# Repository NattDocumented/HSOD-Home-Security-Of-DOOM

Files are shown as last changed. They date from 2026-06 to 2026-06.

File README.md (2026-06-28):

# H.S.O.D. : Home Security Of DOOM

A simple home security alarm with personality and a little twist ***wink*** ***wink***.

## What is it?

It is just like your simple, ordinary home security/alarm system. If you input your PIN to arm or disarm the alarm, and if you proceed to enter your PIN just in time, the alarm won't go off. However, when H.S.O.D went off... It doesn't just play a normal alarm... I will scare the burglar away (hopefully)... it plays a pre-recorded audio which you can customize/add custom audio to your liking, of how you would like to torment your burglar.

My personal option is DOOM ETERNAL MUSIC INTRO with + "so you are the chosen one."

## How do you use it?

It is very simple, here's how to use it!

### 1. Arming the Device
* **Action:** On boot, the system is disarmed. Input the PIN.
* **Outcome:** The current state of the device will change from unarmed to armed, and the OLED display and an audio cue from the speaker will indicate that!

### 2. INTRUDER ALERT!!!
* **Action:** Human detected.
* **Outcome:** The device enters a warning state or a countdown state, to be exact. The OLED display and a countdown coming from the speaker tracking your remaining time will also indicate that!

### 3. Disarming the Device
* **Action:** Input the PIN.
* **Outcome:**
  * **Correct PIN:** Everything resets and goes back to normal (back to the unarmed/disarmed state), the OLED display and the sound cue will also indicate it as well!
  * **Incorrect PIN:** Everything continues, but you can still go ahead and try again until the countdown reaches zero (but there's also a max attempt)

## System Architecture

```mermaid

graph TD;
  %%Define styles
  classDef controller fill:
  classDef sensor fill:
  classDef output fill:
  classDef cloud fill:

  %% Nodes
  Radar[HLK-LD2410C]:::sensor
  Mic[ICS-43434]:::sensor
  Keypad[Keypad]:::sensor

  MCU[Arduino Nano ESP32]:::controller

  OLED[OLED Display]:::output
  DFPlayer[DFPlayer Mini + Speaker]:::output

  Wit[Wit.ai Speech API]:::cloud

  %% Connections
  Radar --> |UART2 / Pin D11 Trigger| MCU
  Mic --> | I2S Mono PCM via DMA | MCU
  Keypad --> |Digital I/O Pins 2-8| MCU

  MCU --> |Hardware I2C| OLED
  MCU --> |Hardware UART1| DFPlayer
  MCU -.-> |Chunked HTTPS POST| Wit

```

## State Machine

```mermaid

stateDiagram-v2
  [*] --> STATE_DISARMED : Boot

  STATE_DISARMED --> STATE_ARMED : Enter PIN + ENT

  STATE_ARMED --> STATE_COUNTDOWN : Human Detected

  STATE_COUNTDOWN --> STATE_DISARMED : Correct PIN / Voice Phrase <br> Entered 
  STATE_COUNTDOWN --> STATE_ALARM : Timer Hits 0

  STATE_ALARM --> STATE_DISARMED : Correct PIN / Voice Phrase <br> Entered 
  STATE_ALARM --> STATE_LOCKED_OUT : Too Many Failed Attempts

  STATE_LOCKED_OUT --> STATE_ARMED  

```

## Why did I make it?

Here's a little back story. I passed an entrance exam to one of the best high schools in Thailand (Triam Udom Suksa School, btw ***wink*** ***wink***), which means I have to move away and live alone in the big city, but, being a country boy, I came up with an idea. Wouldn't it be so fitting to add some security measures to my apartment because I'm living alone? Normal Securities are boring, corporate, no personality, there's nothing interesting, so I came up with something new of my own! I came up with this!

## Step-By-Step Build Guide.

### Tools Required
* **Soldering Iron & Solder Wire** 
* **Wire Flush Cutters**
* **Tweezers**

---

### [1] : Prep Your MicroSD Card

1. Insert your **MicroSD card** into your computer and format it to **FAT32**.
2. Drop your custom audio files inside (`0001.mp3`, `0002.mp3`, etc.)
   
   *  `0001.mp3` = Warning beep
   *  `0002.mp3` = Full alarm audio
   *  `0003.mp3` = Armed sound
   *  `0004.mp3` = Disarmed sound
   *  `0005.mp3` = Incorrect sound
   *  `0006.mp3` = Locked out sound
   *  `0007.mp3` = Startup sound

3. Eject the card and insert it right into the slot of the **DFPlayer Mini (U3)**.

### [2] : Soldering Components

This is fairly simple due to each component having its own designated spots on the board; simply find those and solder them in place.

**For Example/Demonstration:**
1. **Keypad:** Insert the 12 **Cherry MX Mechanical Switches (SW1 to SW12)** into the **big key grid squares** on the board. If you can't see it, I'm going to assume you're blind (I'm just playing with ya lol), flip it over, and solder, **simple!**
2. **Modules:** as stated, the OLED Display, Arduino Nano ESP32, HLK-LD2410C, and all the components and modules all have their own slot, just insert them into their own spot, **flip 'em over, and solder!** **simple!**

I think you get it now, simple! Isn't it?
All you have to do is do the same thing for every component of this device.

**Tips, but kind of necessarily:** After soldering everything, use your **Wire Flush Cutters** to cut the excess leads or pins off.

### [3] : Uploading Firmware (PlatformIO)

This project is built using **PlatformIO** which is inside of VS Code instead of the standard Arduino IDE. Here's how to flash the firmware:

#### 1. Clone the Project

```bash
git clone https://github.com/NattDocumented/HSOD-Home-Security-Of-DOOM.git
```

#### 2. Open in VS Code
1. Launch **Visual Studio Code**.
2. Make sure you have the **PlatformIO IDE** extension installed; if not, go ahead and install it.
3. Click `File` > `Open Folder...` from the top menu, navigate to the folder you just cloned, and click **Open**. (Make sure you open the root folder containing the `platformio.ini` file)

#### 3. Making Voice Unlock Works

1. Login to [Wit.ai](https://wit.ai) with your Meta (a.k.a. Facebook) account.
2. If done correctly, it should lead you to the dashboard/apps, if not [click this](https://wit.ai/apps).
3. Click **+ New App** to create a new app **(obviously)**. You can name it whatever you please, but I personally just named it `"hsod"`.
4. Go into your newly created app. You'll see a sidebar. Click on **Management**, and go to **Settings**.
5. Copy your **Client Access Token** and replace these line in the firmware's code.
   
    ```cpp
    const char* WIFI_SSID = "YOUR_WIFI_SSID"; // Your WiFi's SSID
    const char* WIFI_PASS = "YOUR_WIFI_PASSWORD"; // Your WiFi Password here
    const char* WIT_TOKEN = "YOUR_WIT_AI_TOKEN"; // Your Wit.ai's token here
    ```

#### 4. Build and Upload
1. Connect a USB-C data cable from your computer into your Arduino Nano ESP32 port.
2. Click the **PlatformIO Alien Icon** on the left menu bar.
3. Under the Project Tasks menu, click **Build** to compile the codebase.
4. Once the terminal displays a green `[SUCCESS]` message, click **Upload** right below it to flash the firmware onto your board.

#### 5. Done
As soon as the upload completes, the OLED screen will wake up, and the speaker will play the system startup sound.

### [4] : Casing / Enclosure

After finishing the other steps, I think this one is the easiest, so don't be tired yet, lmao.

1. **Have your 3D printed casing / Enclosure ready:** if you haven't done that, go ahead and print it, no rush, because this README.md can't run away from you lmao.
2. **Assemble:** This is easy. There should be 2 parts: the base and the lid. Since there are poles on the base and holes on the PCB for assembly, simply insert the PCB into the enclosure while making sure the USB of the Arduino Nano ESP32 is right where the hole for the USB on the casing is. After, just put the base and lids together while making sure all the components that should be visible are visible. Both the base and the lid have sockets for connecting to each other.
3. **Done!**

#### You can now enjoy this amazing device. Hope you have a great experience. Any feedback is appreciated.

## Gallery

### Finished Product Renders
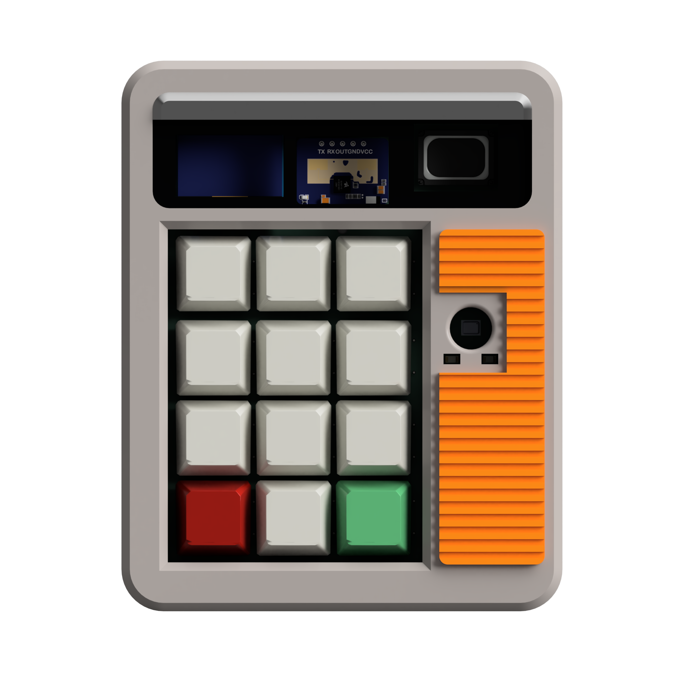
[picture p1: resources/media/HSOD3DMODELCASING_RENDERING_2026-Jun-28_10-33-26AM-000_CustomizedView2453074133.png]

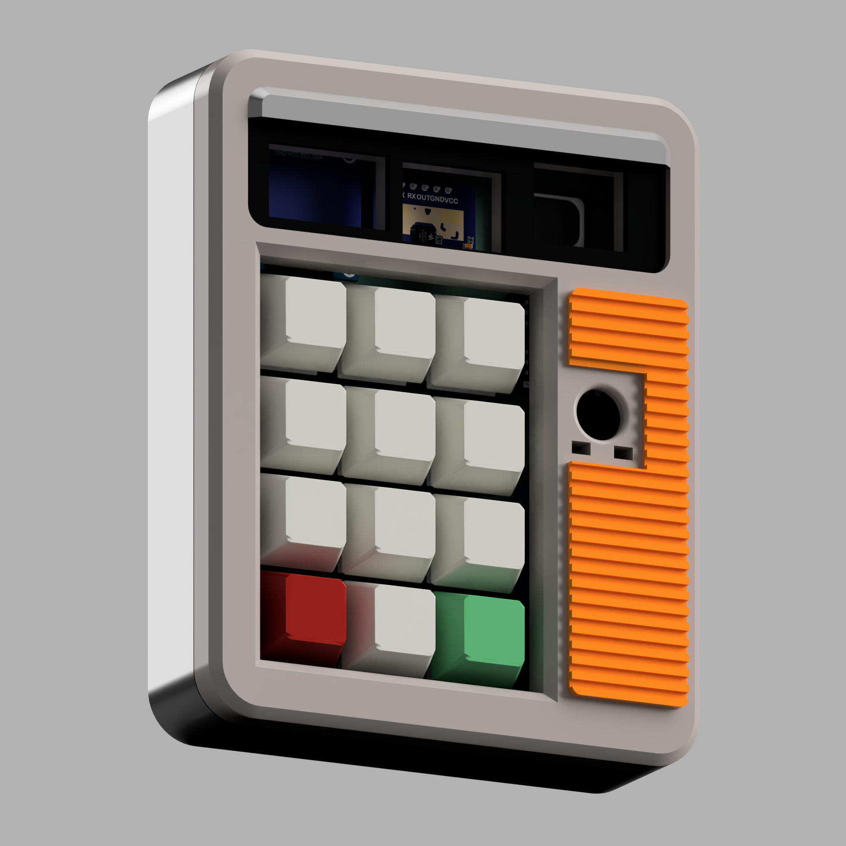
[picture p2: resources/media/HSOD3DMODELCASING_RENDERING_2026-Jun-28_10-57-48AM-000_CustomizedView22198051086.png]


### Schematics

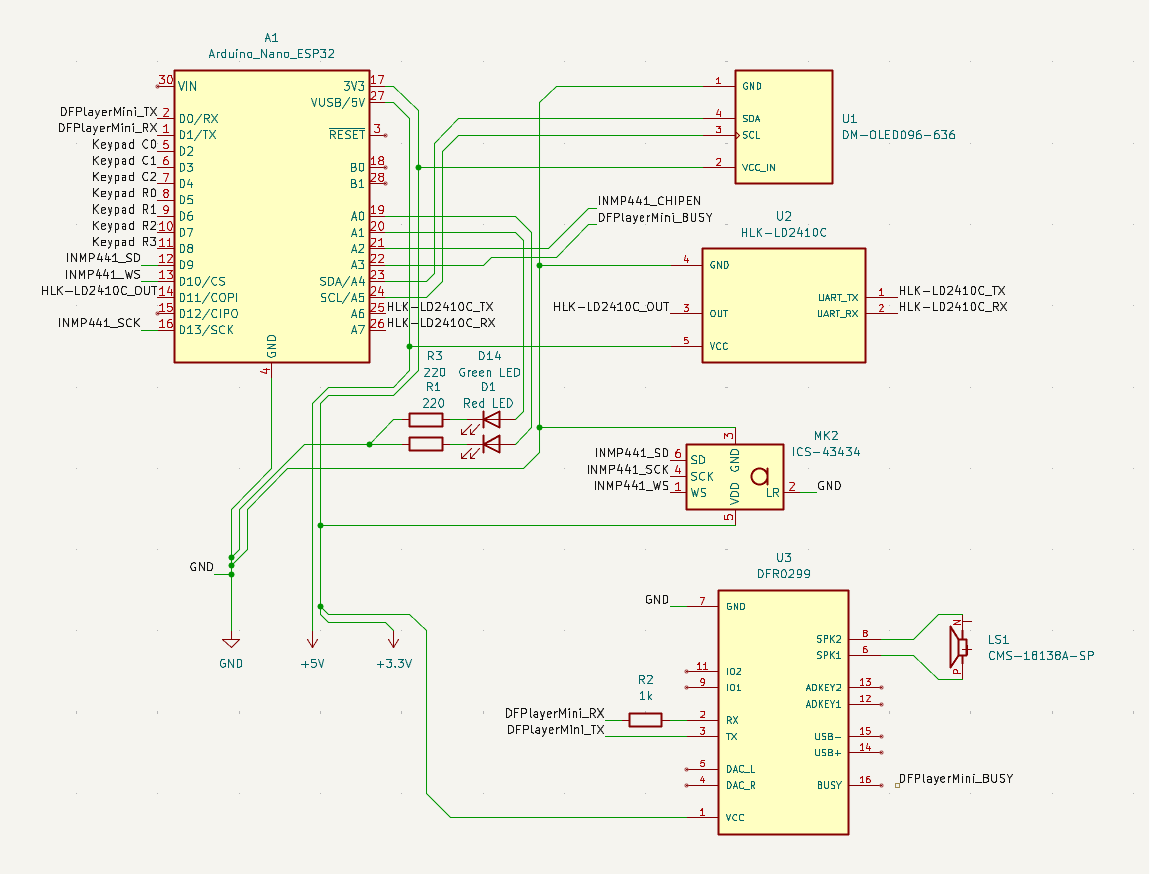
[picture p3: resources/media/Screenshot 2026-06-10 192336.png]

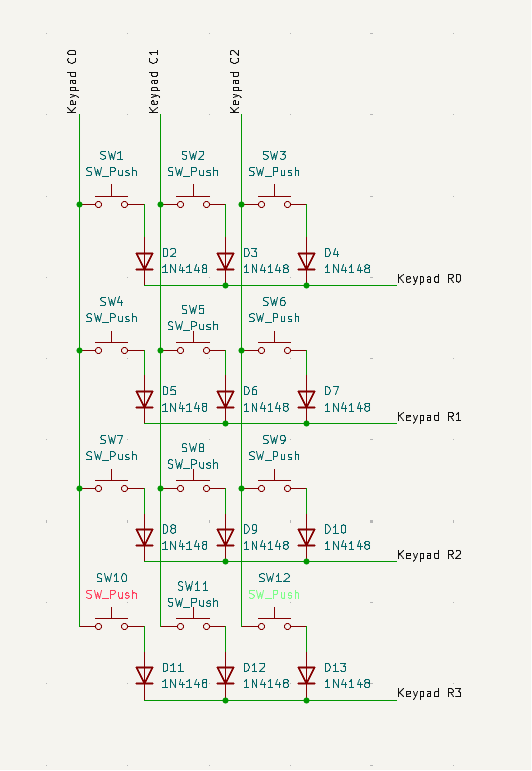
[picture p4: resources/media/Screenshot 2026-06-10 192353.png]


### PCBs

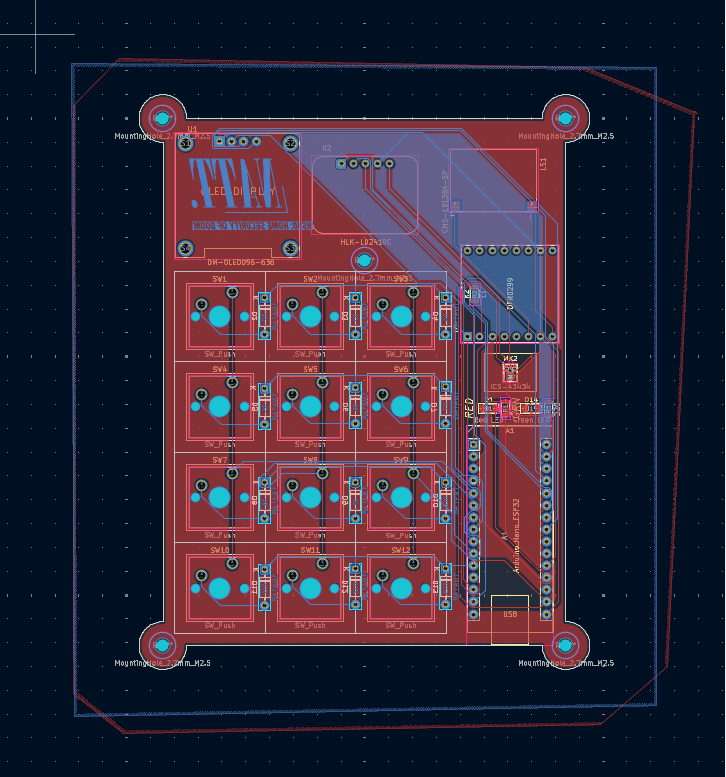
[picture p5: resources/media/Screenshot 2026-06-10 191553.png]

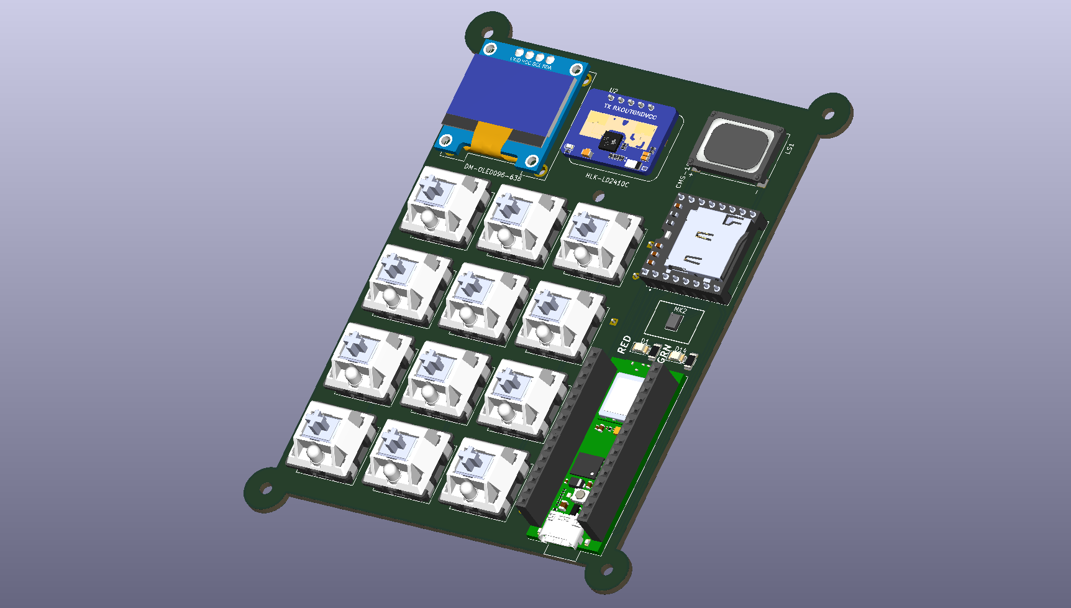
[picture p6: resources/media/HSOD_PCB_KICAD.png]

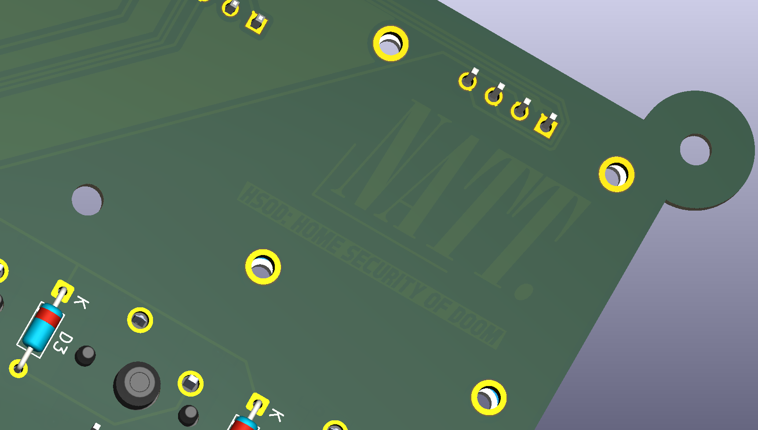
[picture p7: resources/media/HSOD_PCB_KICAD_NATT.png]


### Casing / Enclosure Design

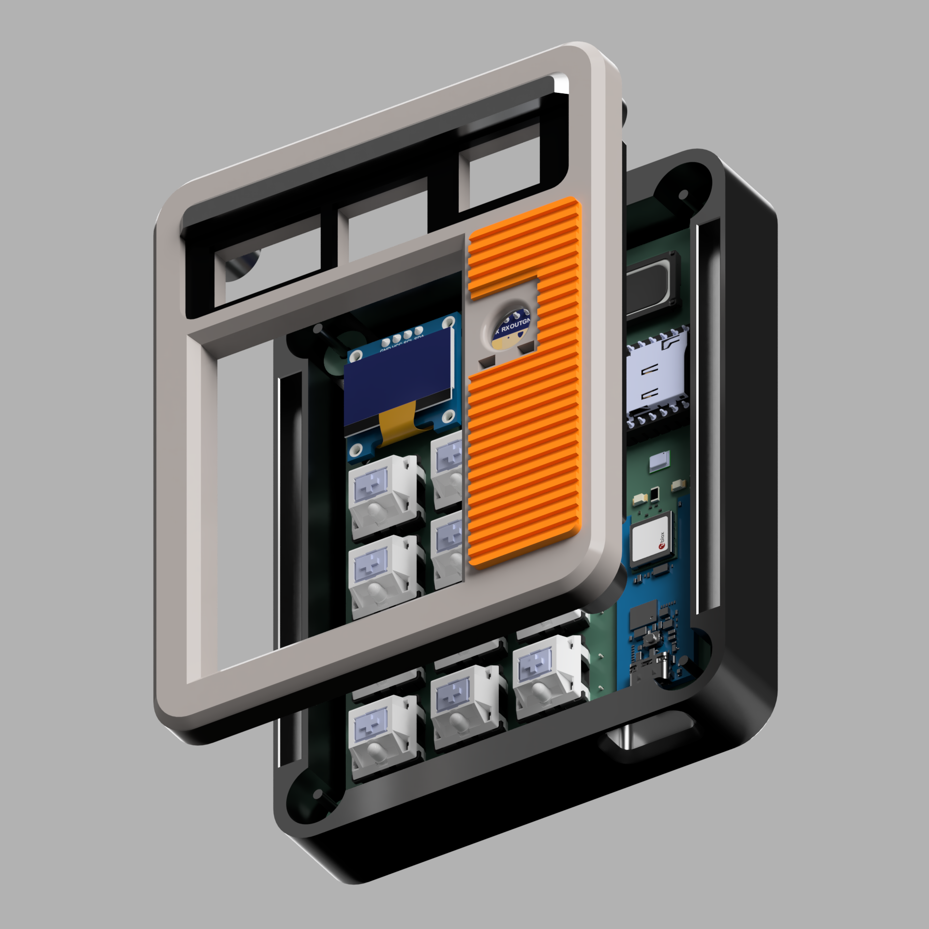
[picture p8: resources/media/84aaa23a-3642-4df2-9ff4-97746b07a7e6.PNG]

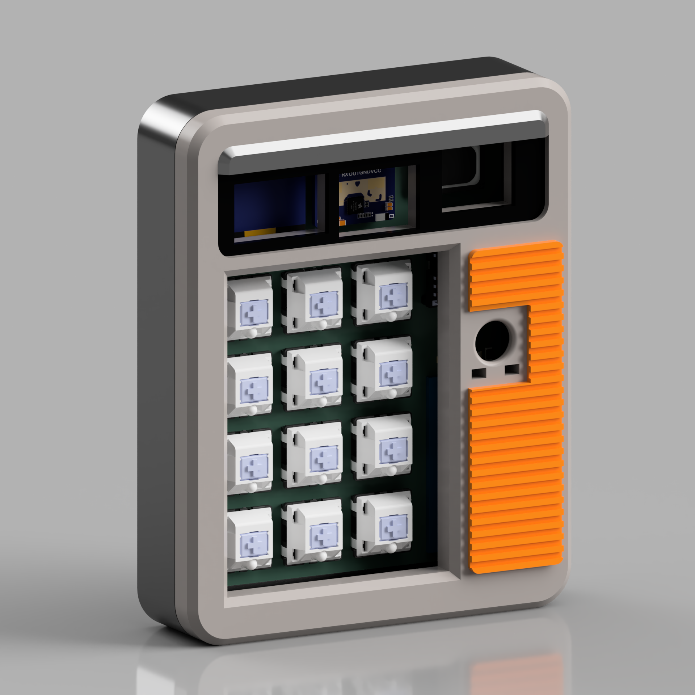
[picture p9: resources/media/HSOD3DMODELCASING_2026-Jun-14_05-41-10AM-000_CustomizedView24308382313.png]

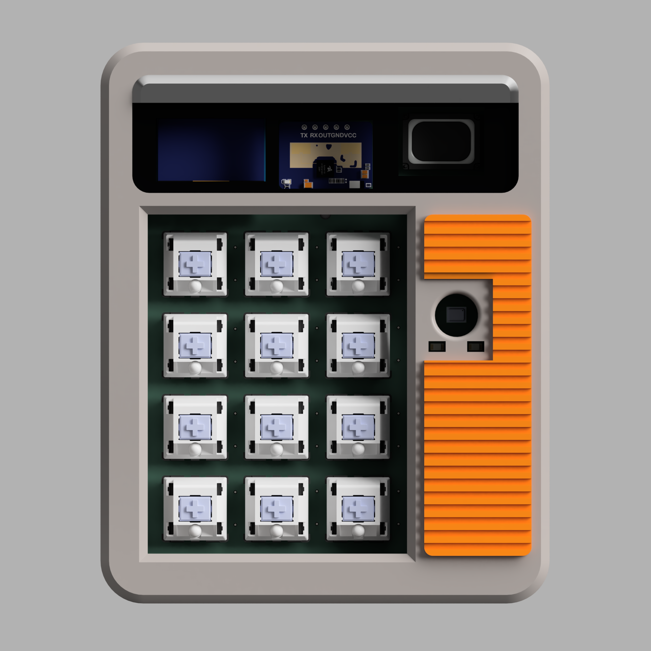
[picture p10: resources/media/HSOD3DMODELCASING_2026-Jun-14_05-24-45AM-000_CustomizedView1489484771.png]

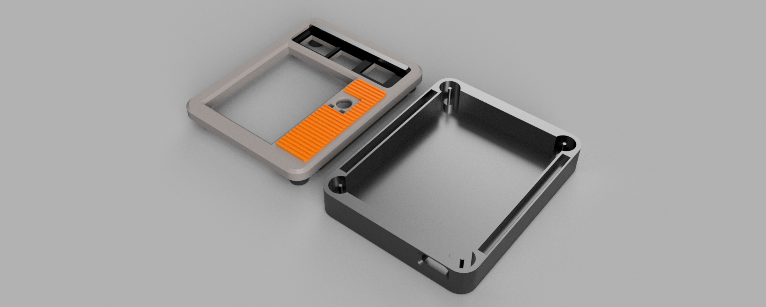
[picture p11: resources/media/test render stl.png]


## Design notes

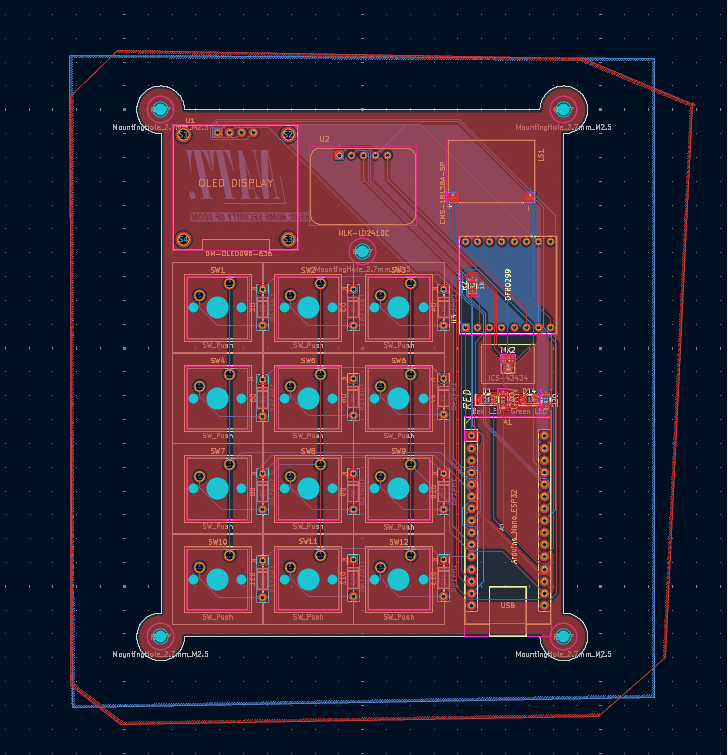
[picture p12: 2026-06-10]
resources/media/Screenshot 2026-06-10 191414.png

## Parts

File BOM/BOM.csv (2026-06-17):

Name/Value | Qty | Qty (pcs) | Reference | Footprint | Source | Datasheet | Unit Cost (USD) | Total Line Cost (USD)
Arduino Nano ESP32 | 1 | 1 | A1 | Module:Arduino_Nano | https://th.aliexpress.com/item/1005010222434725.html?curPageLogUid=WB2ngV9cbQay | https://docs.arduino.cc/resources/datasheets/ABX00083-datasheet.pdf | $20.42 | $20.42
1N4148 Switching Diodes (100 pcs) | 1 | 12 | D2,D3,D4,D5,D6,D7,D8,D9,D10,D11,D12,D13 | Diode_THT:D_DO-35_SOD27_P7.62mm_Horizontal | https://th.aliexpress.com/item/1005008546139991.html?curPageLogUid=1k5XOGo850Vm | https://assets.nexperia.com/documents/data-sheet/1N4148_1N4448.pdf | $0.61 | $0.61
LED SMD (5 color: Red,Green,Blue,White,Yellow | 100 pcs | 20 pcs/color) | 1 | 2 | D14 (Green),D1 (Red) | LED_SMD:LED_1206_3216Metric | https://th.aliexpress.com/item/1005010516045797.html?curPageLogUid=vBj5sSL6c7mr | https://cdn-reichelt.de/documents/datenblatt/A500/SMD1206_ENG_TDS.pdf | $1.17 | $1.17
8 Ohm 1W (CMS-18138A-SP) | 1 | 1 | LS1 | CMS-18138A-SP:CUI_CMS-18138A-SP | https://www.mouser.com/ProductDetail/Same-Sky/CMS-18138A-SP?qs=EU6FO9ffTweZnPPJ%252Bd4HzA%3D%3D | https://th.mouser.com/datasheet/3/6118/1/cms_18138a_sp.pdf | $4.25 | $4.25
ICS-43434 Digital I2S Microphone | 1 | 1 | MK2 | Sensor_Audio:InvenSense_ICS-43434-6_3.5x2.65mm | https://th.mouser.com/ProductDetail/TDK-InvenSense/ICS-43434?qs=u4fy%2FsgLU9PAgmWRI7%252BqXA%3D%3D | https://www.invensense.com/wp-content/uploads/2016/02/DS-000069-ICS-43434-v1.2.pdf | $3.27 | $3.27
220 Ohm Resistors (300 pcs) | 2 | 2 | R1,R3 | Resistor_SMD:R_1206_3216Metric | https://th.aliexpress.com/item/1005011756381896.html?curPageLogUid=rDaOGspg5KaQ | https://www.vishay.com/docs/60093/fcseries.pdf | $1.31 | $2.62
1k Ohm Resistor (300 pcs) | 1 | 1 | R2 | Resistor_SMD:R_1206_3216Metric | https://th.aliexpress.com/item/1005011756381896.html?curPageLogUid=rDaOGspg5KaQ | https://www.vishay.com/docs/60093/fcseries.pdf | $1.33 | $1.33
Cherry MX Mechanical Switches (No RGB,10 pcs) | 2 | 12 | SW1,SW2,SW3,SW4,SW5,SW6,SW7,SW8,SW9,SW10,SW11,SW12 | Button_Switch_Keyboard:SW_Cherry_MX_1.00u_PCB | https://th.aliexpress.com/item/1005007891400560.html?curPageLogUid=uYAcDnG8VaiJ | https://cdn.sparkfun.com/datasheets/Components/Switches/MX%20Series.pdf | $3.64 | $7.28
0.96" I2C 128X64 SSD1306 OLED Display | 1 | 1 | U1 | Oled from idk 001:MODULE_DM-OLED096-636 | https://th.aliexpress.com/item/32896971385.html?curPageLogUid=fn6mKh68Id5Y | - | $1.23 | $1.23
HLK-LD2410C 24GHz Radar Module | 1 | 1 | U2 | HLK-LD2410C:MODULE_HLK-LD2410C | https://th.aliexpress.com/item/1005005047841163.html?curPageLogUid=WBC80ioCXF8C | https://drive.google.com/drive/folders/1ypOlacBmmFXY6lDQ0f1hEJFmczNe-0WG | $1.51 | $1.51
DFPlayer Mini (DFR0299) | 1 | 1 | U3 | DFR0299:MODULE_DFR0299 | https://th.aliexpress.com/item/1005006166800318.html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 | https://dfimg.dfrobot.com/wiki/20532/DFR0299_mp3-player-module_datasheet_V1.0.pdf | $1.07 | $1.07
SanDisk Ultra MicroSD Card 32GB | 1 | 1 | - | - | https://th.aliexpress.com/item/1005007498167692.html?curPageLogUid=lMcXFdEWEGLv | - | $7.61 | $7.61
PCB Fabrication | 1 | 1 | - | - | https://jlcpcb.com/quote | - | $8.60 | $8.60
 |  |  |  |  |  | Estimated total cost (USD): | $60.97

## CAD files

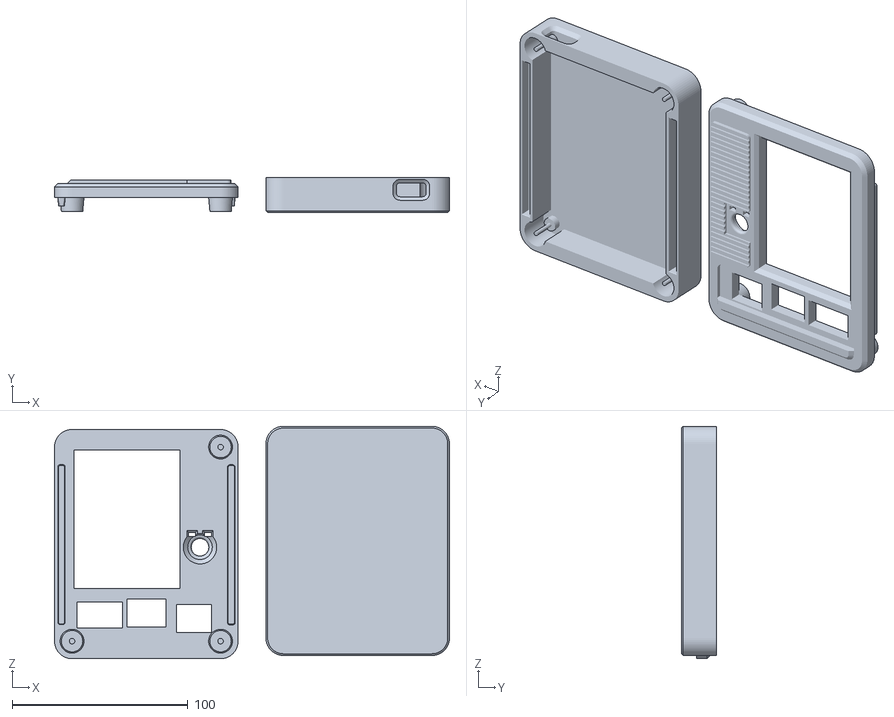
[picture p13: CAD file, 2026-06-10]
STLs/hsod_case_1printfinish.stl
225.0 x 20.0 x 132.4

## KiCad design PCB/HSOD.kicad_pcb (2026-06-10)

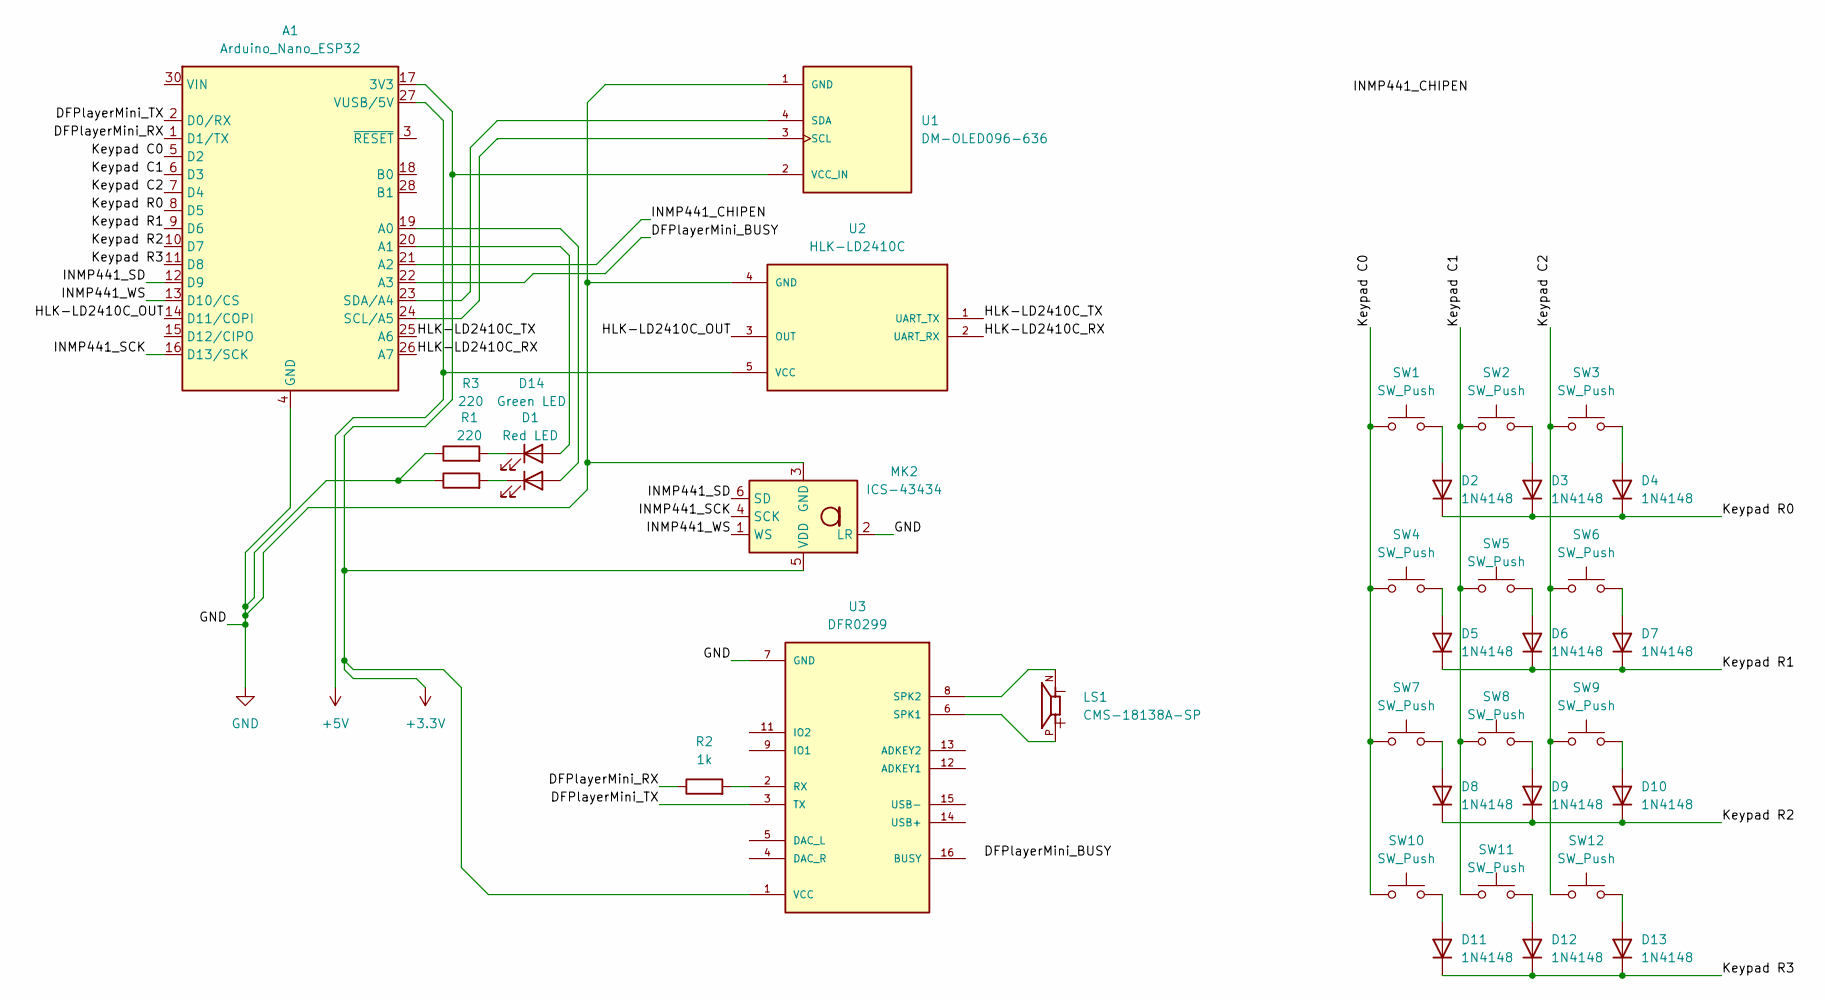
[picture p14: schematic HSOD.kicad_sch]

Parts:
A1: Arduino_Nano_ESP32; Arduino_Nano
D1: Red LED; LED_1206_3216Metric
D2, D3, D4, D5, D6, D7, D8, D9, D10, D11, D12, D13: 1N4148; D_DO-35_SOD27_P7.62mm_Horizontal
D14: Green LED; LED_1206_3216Metric
LS1: CMS-18138A-SP; CUI_CMS-18138A-SP
MK2: ICS-43434; InvenSense_ICS-43434-6_3.5x2.65mm
R1, R3: 220; R_1206_3216Metric
R2: 1k; R_1206_3216Metric
SW1, SW2, SW3, SW4, SW5, SW6, SW7, SW8, SW9, SW10, SW11, SW12: SW_Push; SW_Cherry_MX_1.00u_PCB
U1: DM-OLED096-636; MODULE_DM-OLED096-636; PARTREV 2018-09-10
U2: HLK-LD2410C; MODULE_HLK-LD2410C; PARTREV V1.00
U3: DFR0299; MODULE_DFR0299

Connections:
+3.3V: A1.17 (3V3), MK2.5 (VDD), U1.2 (VCC_IN), U3.1 (VCC)
+5V: A1.27 (VUSB/5V), U2.5 (VCC)
/DFPlayerMini_BUSY: A1.22 (A3)
/DFPlayerMini_RX: A1.1 (D1/TX), R2.1
/DFPlayerMini_TX: A1.2 (D0/RX), U3.3 (TX)
/HLK-LD2410C_OUT: A1.14 (D11/COPI), U2.3 (OUT)
/HLK-LD2410C_RX: A1.26 (A7), U2.2 (UART_RX)
/HLK-LD2410C_TX: A1.25 (A6), U2.1 (UART_TX)
/INMP441_CHIPEN: A1.21 (A2)
/INMP441_SCK: A1.16 (D13/SCK), MK2.4 (SCK)
/INMP441_SD: A1.12 (D9), MK2.6 (SD)
/INMP441_WS: A1.13 (D10/CS), MK2.1 (WS)
/Keypad C0: A1.5 (D2), SW1.1, SW4.1, SW7.1, SW10.1
/Keypad C1: A1.6 (D3), SW2.1, SW5.1, SW8.1, SW11.1
/Keypad C2: A1.7 (D4), SW3.1, SW6.1, SW9.1, SW12.1
/Keypad R0: A1.8 (D5), D2.1 (K), D3.1 (K), D4.1 (K)
/Keypad R1: A1.9 (D6), D5.1 (K), D6.1 (K), D7.1 (K)
/Keypad R2: A1.10 (D7), D8.1 (K), D9.1 (K), D10.1 (K)
/Keypad R3: A1.11 (D8), D11.1 (K), D12.1 (K), D13.1 (K)
GND: A1.4 (GND), A1.29 (GND), MK2.2 (LR), MK2.3 (GND), R1.1, R3.1, U1.1 (GND), U2.4 (GND), U3.7 (GND), U3.10 (GND)
unnamed: A1.19 (A0), D1.2 (A)
unnamed: A1.20 (A1), D14.2 (A)
unnamed: A1.24 (SCL/A5), U1.3 (SCL)
unnamed: A1.23 (SDA/A4), U1.4 (SDA)
unnamed: D1.1 (K), R1.2
unnamed: D2.2 (A), SW1.2
unnamed: D3.2 (A), SW2.2
unnamed: D4.2 (A), SW3.2
unnamed: D5.2 (A), SW4.2
unnamed: D6.2 (A), SW5.2
unnamed: D7.2 (A), SW6.2
unnamed: D8.2 (A), SW7.2
unnamed: D9.2 (A), SW8.2
unnamed: D10.2 (A), SW9.2
unnamed: D11.2 (A), SW10.2
unnamed: D12.2 (A), SW11.2
unnamed: D13.2 (A), SW12.2
unnamed: D14.1 (K), R3.2
unnamed: R2.2, U3.2 (RX)
unnamed: LS1.P, U3.6 (SPK1)
unnamed: LS1.N, U3.8 (SPK2)

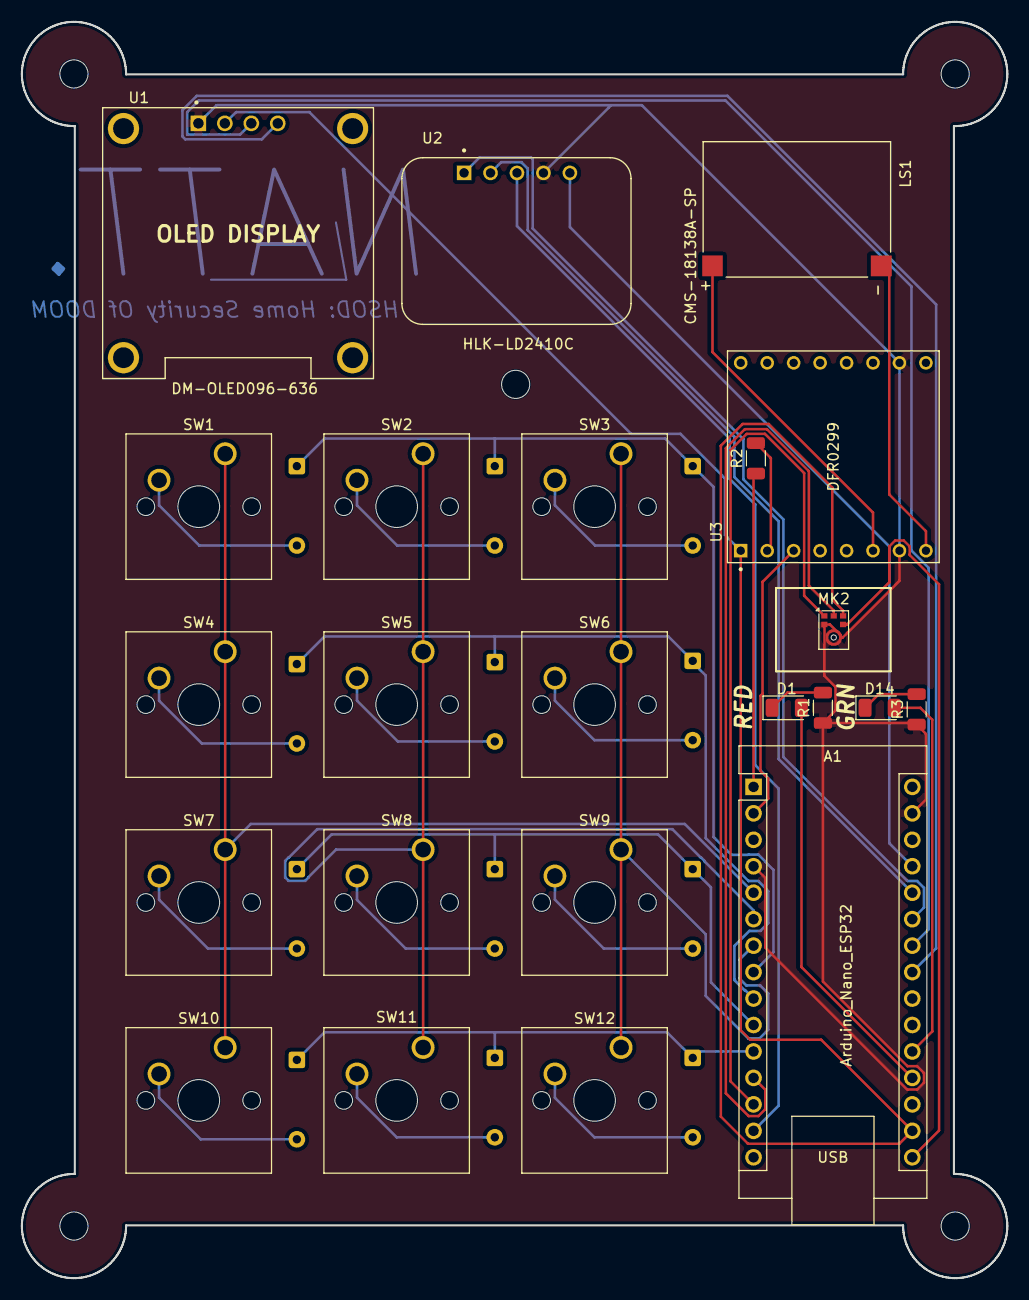
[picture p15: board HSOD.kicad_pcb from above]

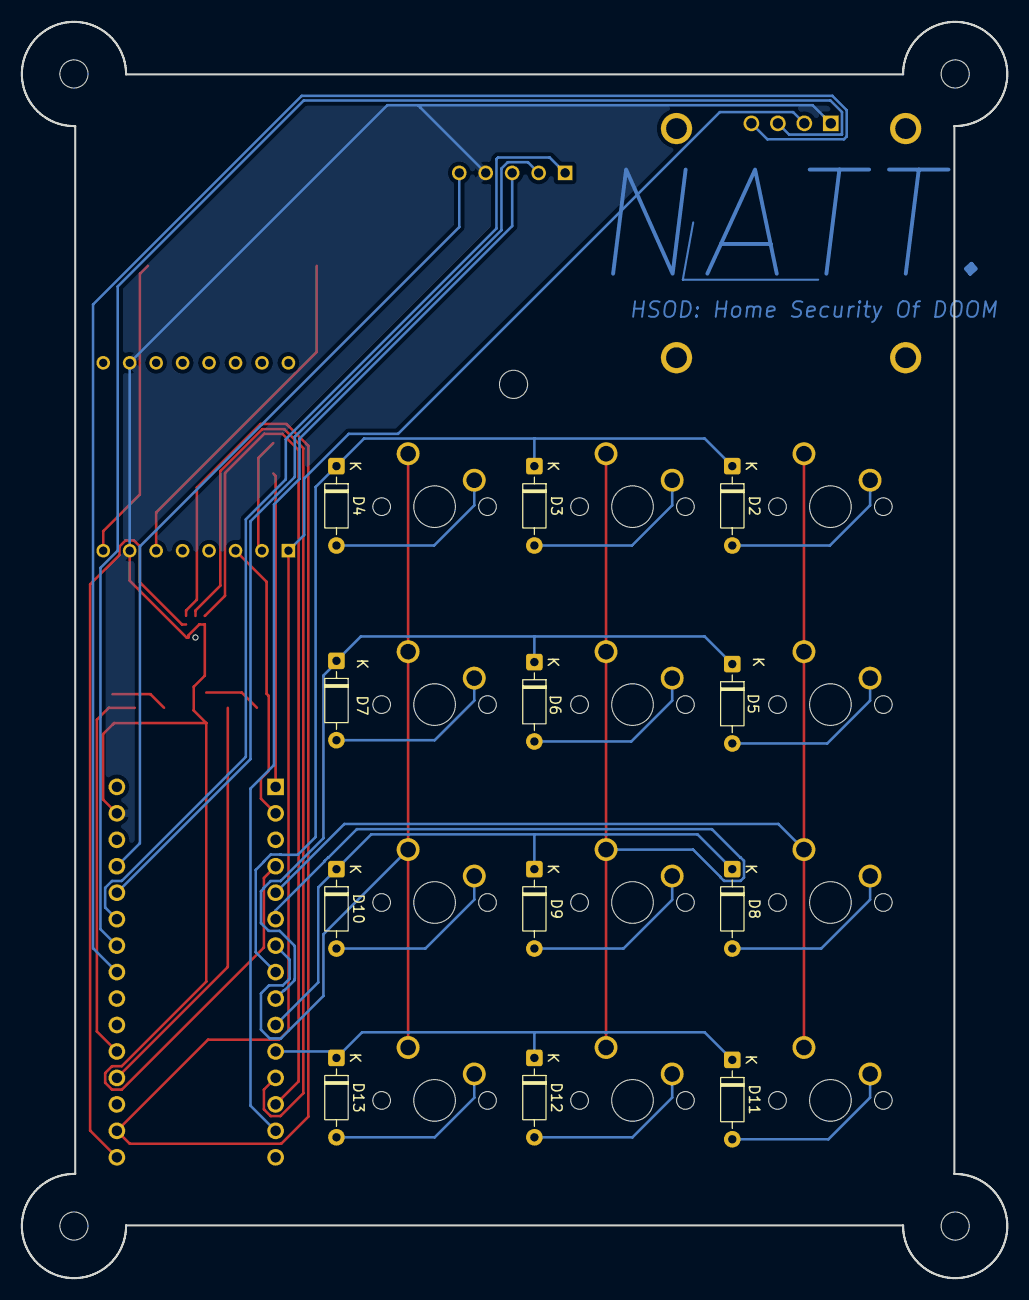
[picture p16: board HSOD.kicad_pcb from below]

Board: 2 copper layers, 94.6 x 120.6 mm, 35 parts (12 on the bottom side), 39 nets.

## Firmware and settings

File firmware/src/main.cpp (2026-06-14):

#include <Arduino.h>
#include <Keypad.h>
#include <Wire.h>
#include <Adafruit_GFX.h>
#include <Adafruit_SSD1306.h>
#include <HardwareSerial.h>
#include <DFRobotDFPlayerMini.h>
#include <ld2410.h>
#include <WiFi.h>
#include <WiFiClientSecure.h>
#include <HTTPClient.h>
#include <driver/i2s.h>

// --------------------- //
// ---- DEFINE PINS ---- //
// --------------------- //

// OLED Display
#define PIN_SDA       A4
#define PIN_SCL       A5

// DFPlayerMini
#define PIN_DF_TX     D0 // (ESP32 TX - DFPlayerMini RX)
#define PIN_DF_RX     D1 // (ESP32 RX - DFPLayerMini TX)

// HLK-LD2410C
#define PIN_LD_TX     A7 // (ESP32 TX - RX)
#define PIN_LD_RX     A6 // (ESP32 RX - TX)
#define PIN_LD_OUT    D11

// ICS-43434
#define PIN_I2S_WS    D10
#define PIN_I2S_SD    D9
#define PIN_I2S_SCK   D13

// LED
#define PIN_LED_RED   A0
#define PIN_LED_GREEN A1

// ---------------- //
// ---- Keypad ---- //
// ---------------- //

const byte KP_ROWS = 4;
const byte KP_COLS = 3;

// LAYOUT
char keys[KP_ROWS][KP_COLS] = {
  {'1', '2', '3'},
  {'4', '5', '6'},
  {'7', '8', '9'},
  {'C', '0', 'E'}   // C - Cancel, E - Enter
};

byte rowPins[KP_ROWS] = {5, 6, 7, 8}; // R0 - R3
byte colPins[KP_COLS] = {2, 3, 4}; // C0 - C2

// ---------------------- //
// ---- VOICE UNLOCK ---- //
// ---------------------- //

const char* WIFI_SSID = "YOUR_WIFI_SSID"; // Your WiFi's SSID
const char* WIFI_PASS = "YOUR_WIFI_PASSWORD"; // Your WiFi Password here
const char* WIT_TOKEN = "YOUR_WIT_AI_TOKEN"; // Your Wit.ai's token here

#define SAMPLE_RATE     16000
#define RECORD_MS       3000
#define RECORD_BYTES    (SAMPLE_RATE * (RECORD_MS/1000) * 2)
#define VOICE_THRESHOLD 1500

bool voiceUnlockEnabled = false;
unsigned long lastVoiceCheck = 0;

// ------------------ //
// ---- SETTINGS ---- //
// ------------------ //

const String PIN = "159753";
const int MAX_PIN_ATTEMPTS = 3;
const int countdown_before_alarm = 10;

// -------------------------- //
// ---- MP3 FILES CONFIG ---- //
// -------------------------- //

#define MP3_BEEP_WARNING  1 // short beep during countdown
#define MP3_ALARM_FULL    2 // The DOOM Music!!!
#define MP3_ARMED         3 // Armed SFX
#define MP3_DISARMED      4 // Disarmed SFX
#define MP3_WRONG_PIN     5 // Incorrect
#define MP3_LOCKED_OUT    6 // Locked
#define MP3_WELCOME       7 // startup
#define MP3_DOOM_SPEECH   8 // "So you are the chosen one."
#define MP3_WELCOME_HOME  9 // "Welcome home master."

// -------------------- //
// ---- COMPONENTS ---- //
// -------------------- //

Adafruit_SSD1306 oled(128, 64, &Wire, -1);
DFRobotDFPlayerMini dfplayer;
Keypad keypad = Keypad(makeKeymap(keys), rowPins, colPins, KP_ROWS, KP_COLS);
ld2410 radar;

//UART PORT SETUP
HardwareSerial serialDF(1); //UART1 for DFPlayerMini
HardwareSerial serialLD(2); //UART2 for HLK-LD2410C

// ---------------- //
// ---- STATES ---- //
// ---------------- //

enum SystemState {
  STATE_DISARMED,
  STATE_ARMED,
  STATE_COUNTDOWN,
  STATE_ALARM,
  STATE_LOCKED_OUT
};

SystemState CurrentState = STATE_DISARMED;

unsigned long stateEnterAt = 0;
unsigned long lastBeepAt = 0;
int PinAttempts = 0;
String EnteredPin = "";
bool HumanPresent = false;
int countdownLeft = countdown_before_alarm;
bool alarmPlaying = false;
unsigned long lastOLEDAt = 0;

// ---- FORWARD DECLARATIONS ---- //
void showOLED(String l1, String l2, String l3, String l4);
String maskPIN(String pin);
void checkPIN();
void configureRadar();
void initVoice();
bool checkVoice();
void disarmByVoice();
uint8_t* recordAudio(size_t &outSize);
bool ensureWiFiConnected();

// --------------- //
// ---- SETUP ---- //
// --------------- //

void setup() {
  Serial.begin(115200);

  // LEDs
  pinMode(PIN_LED_GREEN, OUTPUT);
  pinMode(PIN_LED_RED, OUTPUT);
  digitalWrite(PIN_LED_GREEN, LOW);
  digitalWrite(PIN_LED_RED, LOW);

  // OLED Display
  Wire.begin(PIN_SDA, PIN_SCL);
  if (!oled.begin(SSD1306_SWITCHCAPVCC, 0x3C)) {
    Serial.println("OLED init failed");
  }
  showOLED("Booting...", "", "", "");

  //DFPlayerMini
  serialDF.begin(9600, SERIAL_8N1,  PIN_DF_RX, PIN_DF_TX);
  if (!dfplayer.begin(serialDF)) {
    Serial.println("DFPlayer init failed");
    while(true);
  } else {
    dfplayer.volume(25); //NOTE: Volume is between 0 - 30
    dfplayer.play(MP3_WELCOME);
    Serial.println("DFplayer ready");
  }

  //HLK-LD2410C
  serialLD.begin(256000, SERIAL_8N1, PIN_LD_RX, PIN_LD_TX);
  if (!radar.begin(serialLD)) {
    Serial.println("HLK-LD2410C init failed");
  } else {
    configureRadar();
  }
  
  if (radar.isConnected()) {
    Serial.println("LD2410 is connected!");
    Serial.print("Firmware version: ");
    Serial.print(radar.firmware_major_version);
    Serial.print(".");
    Serial.println(radar.firmware_minor_version);
  }

  //DONE
  showOLED("HSOD: HOME SECURITY OF DOOM", "", "Enter PIN + ENT", "to arm");
  initVoice();
  keypad.setHoldTime(850);
}

// ------------------- //
// ---- MAIN LOOP ---- //
// ------------------- //

void loop() {
  radar.read();
  char key = keypad.getKey();

  switch (CurrentState) {
    case STATE_DISARMED: handleDISARMED(key); break;
    case STATE_ARMED: handleARMED(key); break;
    case STATE_ALARM: handleAlarm(key); break;
    case STATE_COUNTDOWN: handleCountdown(key); break;
    case STATE_LOCKED_OUT: handleLockedOut(key); break;
  }

}

// ------------------------ //
// ---- STATE HANDLERS ---- //
// ------------------------ //

void handleDISARMED(char key) {
  digitalWrite(PIN_LED_GREEN, LOW);
  digitalWrite(PIN_LED_RED, LOW);

  if (key == 'E') {
    if (EnteredPin == PIN) {
      EnteredPin = "";
      CurrentState = STATE_ARMED;
      lastBeepAt = 0;
      countdownLeft = countdown_before_alarm;
      stateEnterAt = millis();
      dfplayer.play(MP3_ARMED);
      showOLED("ARMED", "", "(ㆆ_ㆆ)", "");
    } else {
      EnteredPin = "";
      dfplayer.play(MP3_WRONG_PIN);
      showOLED("DISARMED", "WRONG PIM", "Cannot Arm", "");
      delay(1200);
      showOLED("DISARMED", "", "Enter PIN + ENT", "to arm");
    }
    return;
  }

  if (key == 'C') {
    EnteredPin = "";
    showOLED("DISARMED", "", "Enter PIN + ENT", "to arm");
  } else if (key) {
    EnteredPin += key;
    showOLED("DISARMED", "PIN:", maskPIN(EnteredPin), "");
  }
}

void handleARMED(char key) {
  digitalWrite(PIN_LED_GREEN, LOW);
  digitalWrite(PIN_LED_RED, HIGH);

  // Update every 2s
  if (millis() - lastOLEDAt > 2000) {
    showOLED("ARMED", "", "(ㆆ_ㆆ)", "");
    lastOLEDAt = millis();
  }

  bool outPin = digitalRead(PIN_LD_OUT);
  bool uartDet = radar.isConnected() && radar.presenceDetected();

  if (outPin || uartDet) {
    Serial.println("Human Detected - Activating background Wi-Fi...");

    if (WiFi.status() != WL_CONNECTED) {
      WiFi.begin(WIFI_SSID, WIFI_PASS);
    }

    EnteredPin = "";
    CurrentState = STATE_COUNTDOWN;
    countdownLeft = countdown_before_alarm;
    lastBeepAt = 0;
    lastOLEDAt = 0;
    stateEnterAt = millis();
    showOLED("ENTER CODE", String(countdown_before_alarm) + "s", "PIN: ", "");
    return;
  }
}

void handleAlarm(char key) {
  digitalWrite(PIN_LED_GREEN, LOW);
  digitalWrite(PIN_LED_RED, HIGH);

  if (!alarmPlaying) {
    dfplayer.loop(MP3_ALARM_FULL);
    alarmPlaying = true;
    showOLED("!! INTRUDER ALERT !!", "Hold C for Voice", "PIN:", maskPIN(EnteredPin));
  }

  //Keypad
  if (key == 'C') {
    unsigned long startCheck = millis();
    bool isLongPress = false;

    while (millis() - startCheck < 900) {
      keypad.getKey(); 
      if (keypad.getState() == HOLD) {
        isLongPress = true;
        break;
      }
      if (keypad.getState() == RELEASED) {
        break;
      }
      delay(10);
    }

    if (isLongPress) {
      if (checkVoice()) {
        disarmByVoice();
        return;
      }
    } else {
      EnteredPin = "";
      showOLED("!! INTRUDER ALERT !!", "PIN Cleared", "PIN:", "");
    }
  } else if (key == 'E') {
    checkPIN();
  } else if (key) {
    EnteredPin += key;
    showOLED("!! INTRUDER ALERT !!", "Hold C for Voice", "PIN:", maskPIN(EnteredPin));
  }
}

void handleCountdown(char key) {
  unsigned long now = millis();
  countdownLeft = countdown_before_alarm - (int)((now - stateEnterAt) / 1000);

  //Update OLED
  static int lastShown = -1;
  if (countdownLeft != lastShown) {
    lastShown = countdownLeft;
    showOLED("ENTER CODE", String(countdownLeft) + "s remaining", "Hold C for Voice", "PIN: " + maskPIN(EnteredPin));
  }

  //Beep
  unsigned long beepEvery = (countdownLeft <= 3) ? 500 : 2000;
  if (now - lastBeepAt > beepEvery) {
    dfplayer.play(MP3_BEEP_WARNING);
    lastBeepAt = now;
  }

  //Keypad
  if (key == 'C') {
    unsigned long startCheck = millis();
    bool isLongPress = false;

    while (millis() - startCheck < 900) {
      keypad.getKey();
      if (keypad.getState() == HOLD) {
        isLongPress = true;
        break;
      }
      if (keypad.getState() == RELEASED) {
        break;
      }
      delay(10);
    }

    if (isLongPress) {
      if (checkVoice()) {
        disarmByVoice();
        return;
      }
    } else {
      EnteredPin = "";
      showOLED("ENTER CODE", String(countdownLeft) + "s remaining", "PIN Cleared", "");
      delay(600);
    }
  } else if (key == 'E') {
    checkPIN();
    return;
  } else if (key) {
    EnteredPin += key;
  }

  // Timer ran out yay end of function
  if (countdownLeft <= 0) {
    CurrentState = STATE_ALARM;
    alarmPlaying = false;
    stateEnterAt = millis();
  }
}

void handleLockedOut(char key) {
  digitalWrite(PIN_LED_GREEN, LOW);
  digitalWrite(PIN_LED_RED, HIGH);
  
  unsigned long elapsed = millis( )- stateEnterAt;
  unsigned long remaining = 300000UL - elapsed;
  int minsLeft = remaining / 60000;
  int secsLeft = (remaining % 60000) / 1000;

  if (millis() - lastOLEDAt > 1000) {
    showOLED("LOCKED OUT", "Too many attempts", "Unlocks in: ", String(minsLeft) + "m " + String(secsLeft) + "s");
    lastOLEDAt = millis();
  }

  // back after 5 min
  if (elapsed > 300000UL) {
    PinAttempts = 0;
    CurrentState = STATE_ARMED;
    countdownLeft = countdown_before_alarm;
    lastBeepAt = 0;
    lastOLEDAt = 0;
    stateEnterAt = millis();
  }
}

// ----------------------------------- //
// ---- FUNCTIONS / QOL / HELPERS ---- //
// ----------------------------------- //

void showOLED(String l1, String l2, String l3, String l4) {
  oled.clearDisplay();
  oled.setTextSize(1);
  oled.setCursor(0,0); oled.println(l1);
  oled.setCursor(0, 16); oled.println(l2);
  oled.setCursor(0, 32); oled.println(l3);
  oled.setCursor(0, 48); oled.println(l4);

  oled.display();
}

String maskPIN(String pin) {
  String masked = "";
  for (int i = 0; i < pin.length(); i++) masked += "*";
  return masked;
}

void checkPIN() {
  if (EnteredPin == PIN) {
    // CORRECT
    PinAttempts = 0;
    EnteredPin = "";
    alarmPlaying = false;
    dfplayer.stop();
    dfplayer.play(MP3_DISARMED);
    //dfplayer.play(MP3_WELCOME_HOME);
    CurrentState = STATE_DISARMED;
    stateEnterAt = millis();
    showOLED("DISARMED", "", "Welcome back", "");
  } else {
    // INCORRECT
    PinAttempts++;
    EnteredPin = "";
    dfplayer.play(MP3_WRONG_PIN);

    int left = MAX_PIN_ATTEMPTS - PinAttempts;
    showOLED("WRONG PIN", String(left) + "attempt(s) left", "", "");
    delay(1200);

    if (PinAttempts >= MAX_PIN_ATTEMPTS) {
      dfplayer.play(MP3_LOCKED_OUT);
      CurrentState = STATE_LOCKED_OUT;
      stateEnterAt = millis();
    }
  }
}

void configureRadar() {
  // IDK WHAT I'M DOING IM JUST GUESSING PLEASE CHECK THIS SOON --> Update: Nvm I understand it now...

  if (radar.setMaxValues(4, 3, 5)) {
    Serial.println("Radar range set: 3m moving, 2.25m, stationary");
  } else {
    Serial.println("Radar config failed - fallback to def");
  }

  // Note for reference: values x 0.75 = real world
  // Ex: 4 x 0.75 = 3.0m, 3 x 0.75 = 2.25m... yeah that's it...
}

void initVoice() {
  WiFi.begin(WIFI_SSID, WIFI_PASS);
  Serial.print("Connecting to WiFi");

  unsigned long startWait = millis();
  while (WiFi.status() != WL_CONNECTED && millis() - startWait < 4000) {
    delay(250);
    Serial.print(".");
  }

  if (WiFi.status() == WL_CONNECTED) {
    voiceUnlockEnabled = true;
    Serial.println("\nWiFi OK: " + WiFi.localIP().toString());
    showOLED("WiFi Connected", WiFi.localIP().toString(), "Wit.ai ready", "");
    delay(1500);
  } else {
    voiceUnlockEnabled = false;
    Serial.println("\nWiFi failed");
    showOLED("WiFi Offline:", "Will reconnect", "when triggered", "");
    delay(1250);
  }
}

bool checkVoice() {
  //Check WiFi
  if (WiFi.status() != WL_CONNECTED) {
    if (!ensureWiFiConnected()) {
      showOLED("VOICE ERROR", "WiFi Unreachable", "Use Keypad PIN", "");
      delay(2000);
      return false;
    }
  }

  if (!voiceUnlockEnabled || WiFi.status() != WL_CONNECTED) {
    return false;
  }

  showOLED("LISTENING...", "", "Say the phrase", "");

  // Record audio buffer
  size_t audioSize = 0;
  uint8_t* audioBuffer = recordAudio(audioSize);
  if (!audioBuffer || audioSize == 0) {
    showOLED("Voice Error", "Record Failed", "", "");
    if (audioBuffer) {
      free(audioBuffer);
    }
    return false;
  }

  // Noise Gate
  int16_t* samples = (int16_t*)audioBuffer;
  size_t sampleCount = audioSize / 2;
  int32_t peakVolume = 0;

  for (size_t i = 0; i < sampleCount; i++) {
    int32_t absoluteValue = abs(samples[i]);
    if (absoluteValue > peakVolume) {
      peakVolume = absoluteValue;
    }
  }

  Serial.print("Noise Gate: Peak volume detected");
  Serial.println(peakVolume);

  if (peakVolume < VOICE_THRESHOLD) {
    Serial.println("Noise Gate: Audio too quiet. Aborting.");
    free(audioBuffer);
    delay(1500);
    return false;
  }

  // Raw PCM to Wit.ai (no base64, no WAV header required)
  WiFiClientSecure client;
  client.setInsecure();
  if (!client.connect("api.wit.ai", 443)) {
    showOLED("Wit.ai:", "Connection failed", "", "");
    free(audioBuffer);
    return false;
  }

  String header = "POST /speech?v=20230215 HTTP/1.1\r\n"
                  "HOST: api.wit.ai\r\n"
                  "Authorization: Bearer " + String(WIT_TOKEN) + "\r\n"
                  "Content-Type: audio/raw;encoding=signed-integer;bits=16;rate=" + String(SAMPLE_RATE) + ";endian=little\r\n"
                  "Transfer-Encoding: chunked\r\n"
                  "Connection: close\r\n\r\n";
  client.print(header);

  showOLED("PROCESSING...", "Sending audio...", "", "");

  size_t bytesSent = 0;
  const size_t chunkSize = 512; // 512 bytes at a time could try 256 but idk

  while (bytesSent < audioSize) {
    size_t toSend = audioSize - bytesSent;
    if (toSend > chunkSize) {
      toSend = chunkSize;
    }

    // send chunksize in Hex format + actual data after
    client.printf("%X\r\n", toSend);
    client.write(audioBuffer + bytesSent, toSend);
    client.print("\r\n");

    bytesSent += toSend;
    delay(10);
  }

  client.print("0\r\n\r\n");
  free(audioBuffer);
  showOLED("PROCESSING...", "Analyzing...", "", "");

  String finalResult = "";
  while (client.connected() || client.available()) {
    if (client.available()) {
      String line = client.readStringUntil('\n');
      int textIndex =line.indexOf("\"text\": \"");
      if (textIndex != -1) {
        int start = textIndex + 9;
        int end = line.indexOf("\"", start);
        finalResult = line.substring(start, end);
      }
    }
  }

  client.stop();

  // Check Parse    
  if (finalResult != "") {
    Serial.println("Wit.ai parsed text: " + finalResult);
    finalResult.toLowerCase();

    if (finalResult.indexOf("open sesame") != -1 || finalResult.indexOf("chicken nuggets") != -1) {
      showOLED("ACCESS GRANTED", finalResult, "", "");
      delay(1500);
      return true;
    } else {
      showOLED("ACCESS DENIED", "Phrase wrong: ", finalResult, "");
      delay(2000);
    }
  } else {
    showOLED("Voice Error", "No speech detected", "", "");
    delay(1500);
  }
  
  return false;
}

void disarmByVoice() {
  PinAttempts = 0;
  EnteredPin = "";
  alarmPlaying = false;
  dfplayer.stop();
  dfplayer.play(MP3_DISARMED);
  CurrentState = STATE_DISARMED;
  stateEnterAt = millis();
  showOLED("DISARMED", "", "Voice Unlocked", "");
  Serial.println("Disarmed via voice");
}

uint8_t* recordAudio(size_t &outSize) {
  i2s_config_t cfg = {
    .mode = (i2s_mode_t)(I2S_MODE_MASTER | I2S_MODE_RX),
    .sample_rate = SAMPLE_RATE,
    .bits_per_sample = I2S_BITS_PER_SAMPLE_16BIT,
    .channel_format = I2S_CHANNEL_FMT_ONLY_LEFT,
    .communication_format = i2s_comm_format_t(I2S_COMM_FORMAT_I2S),
    .intr_alloc_flags = 0,
    .dma_buf_count = 4,
    .dma_buf_len = 256,
    .use_apll = false,
  };
  i2s_pin_config_t pins = {
    .bck_io_num = PIN_I2S_SCK,
    .ws_io_num = PIN_I2S_WS,
    .data_out_num = I2S_PIN_NO_CHANGE,
    .data_in_num = PIN_I2S_SD,
  };
  i2s_driver_install(I2S_NUM_0, &cfg, 0, NULL);
  i2s_set_pin(I2S_NUM_0, &pins);
  i2s_start(I2S_NUM_0);
  uint8_t* buf = (uint8_t*)malloc(RECORD_BYTES);
  if (!buf) {
    i2s_driver_uninstall(I2S_NUM_0);
    outSize = 0;
    return nullptr;
  }
  size_t bytesRead = 0, total = 0;
  while (total < RECORD_BYTES) {
    i2s_read(I2S_NUM_0, buf + total, RECORD_BYTES - total,  &bytesRead, portMAX_DELAY);
    total += bytesRead;
  }
  i2s_stop(I2S_NUM_0);
  i2s_driver_uninstall(I2S_NUM_0);
  outSize = total;
  return buf;
}

bool ensureWiFiConnected() {
  if (WiFi.status() == WL_CONNECTED) {
    return true;
  }

  Serial.println("Emergency WiFi Reconnect...");
  showOLED("CONNECTING...", "Waking up WiFi..", "Please wait", "");

  WiFi.disconnect();
  WiFi.begin(WIFI_SSID, WIFI_PASS);

  unsigned long startAttempt = millis();
  while (WiFi.status() != WL_CONNECTED && millis() - startAttempt < 3000) {
    delay(125);
  }

  if (WiFi.status() == WL_CONNECTED) {
    Serial.println("Emergency Reconnect Success");
    voiceUnlockEnabled = true;
    return true;
  }

  Serial.println("Emergency Reconnect Failed");
  return false;
}

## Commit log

2026-06-10 Initial commit
    Commit to kickstart the repo
    [BOM.csv, hsod_case_1printfinish.stl]
2026-06-10 PCBs related
    [HSOD-B_Cu.gbr, HSOD-B_Mask.gbr, HSOD-B_Paste.gbr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]
2026-06-14 Add PIN required for arming
2026-06-17 Update BOM
    [BOM.csv]
2026-06-17 BOM Details
    [BOM.csv]
2026-06-17 Add CAD source files
2026-06-17 Format BOM.csv
    [BOM.csv]
